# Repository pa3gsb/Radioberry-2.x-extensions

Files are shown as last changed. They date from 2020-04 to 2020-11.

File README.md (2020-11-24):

# Radioberry-2.x-extensions
Hardware extensions to the Radioberry Ham Radio

Deepu Augustin VU3TLD, from India made the next step to make a complete stackable HAM radio.

He started with a Power Amplifier board, based on the G6ALU 20W PA; version 1.5 is available and
the first components are in place.

He also is aiming for a filter board; a version 1.3 is available; first PCB's are underway!

An animation of the idea of such a configuration can be found => Radioberry_radio_assembly.avi file.

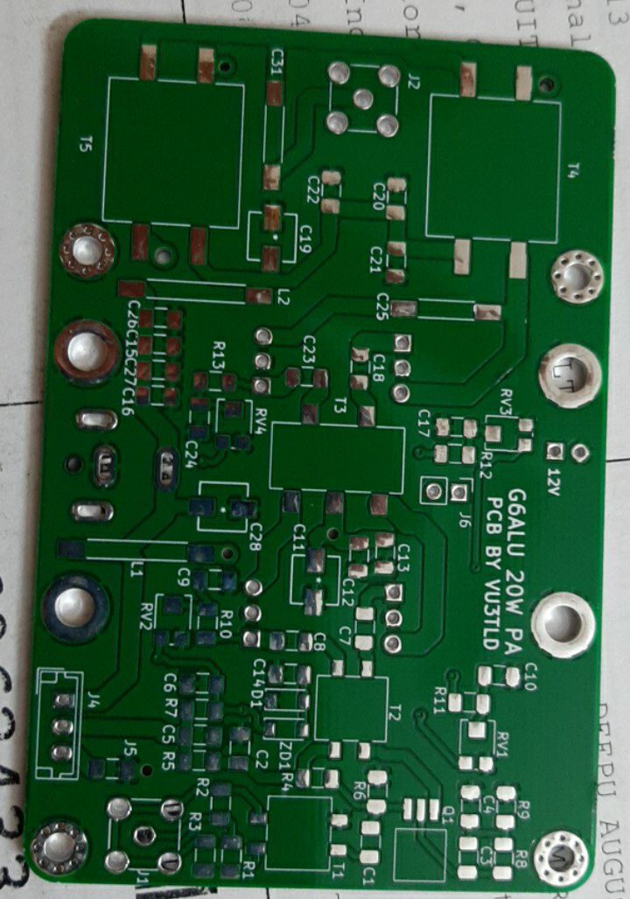
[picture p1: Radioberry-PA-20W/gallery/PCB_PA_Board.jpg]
Radioberry-2.x-extensions

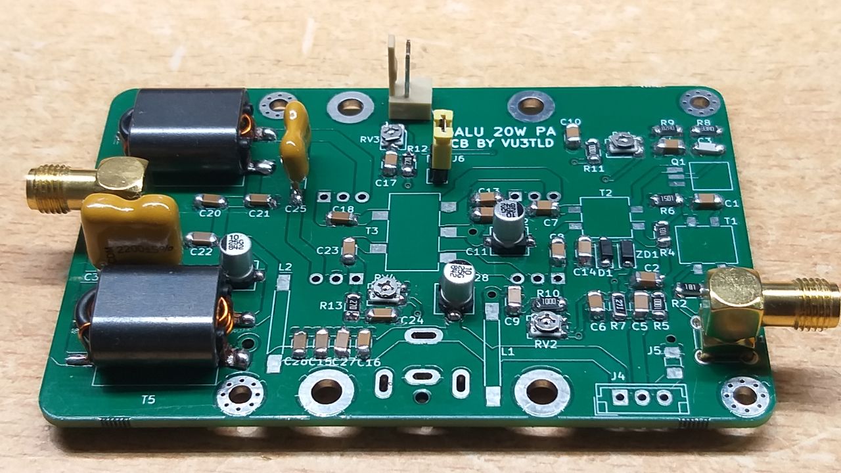
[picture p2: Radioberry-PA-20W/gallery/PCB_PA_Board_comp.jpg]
Radioberry-2.x-extensions

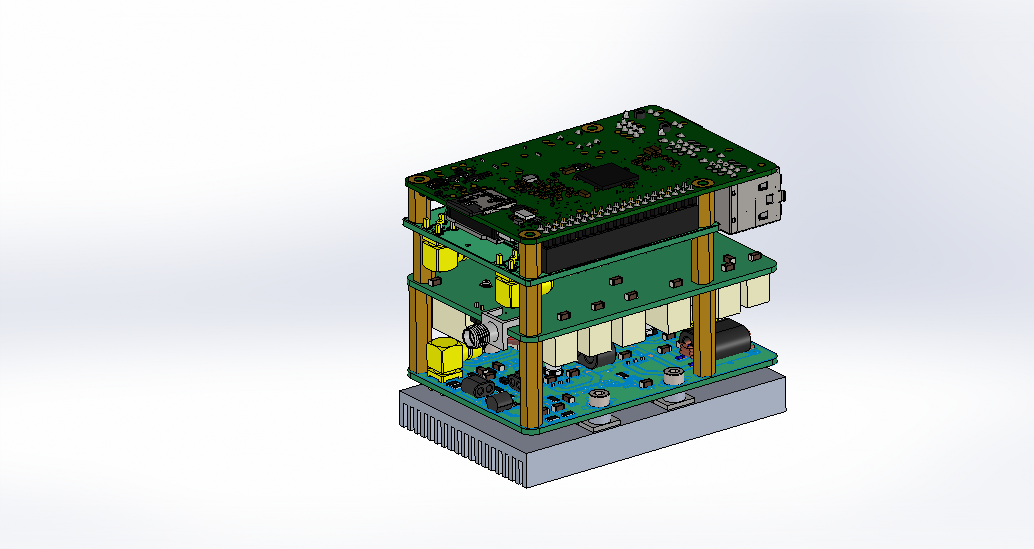
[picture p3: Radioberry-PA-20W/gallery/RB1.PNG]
Radioberry-2.x-extensions

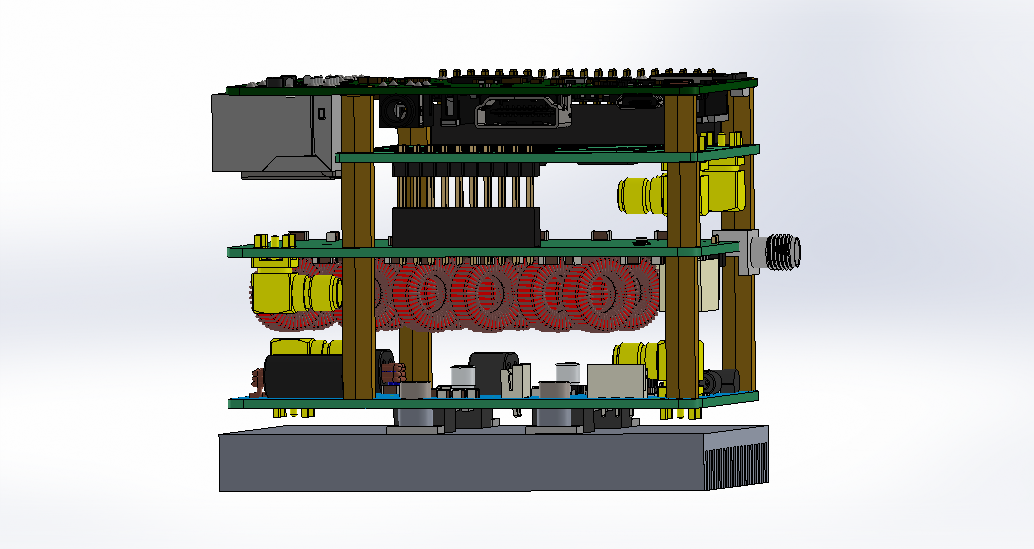
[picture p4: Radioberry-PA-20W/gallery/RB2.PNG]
Radioberry-2.x-extensions

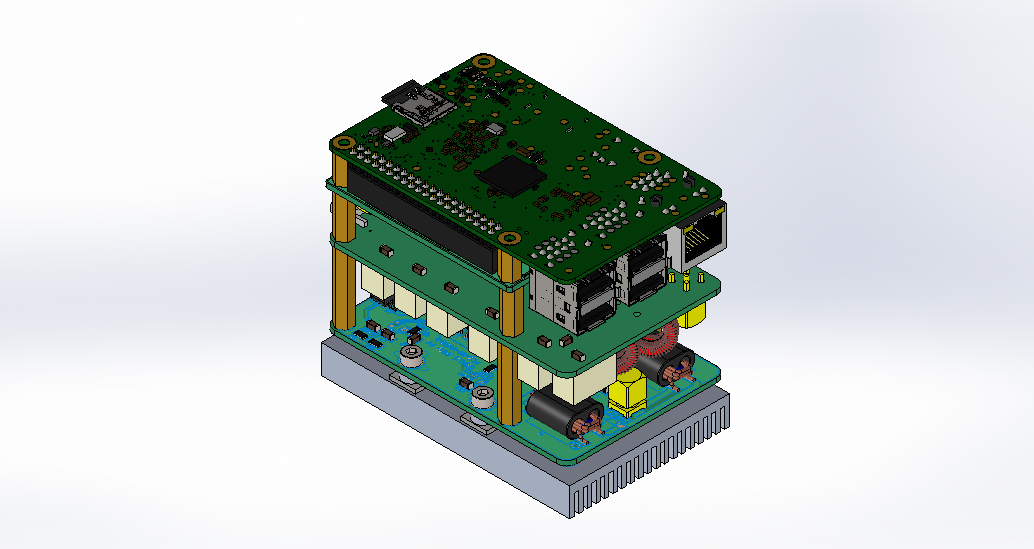
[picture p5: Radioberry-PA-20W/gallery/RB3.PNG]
Radioberry-2.x-extensions

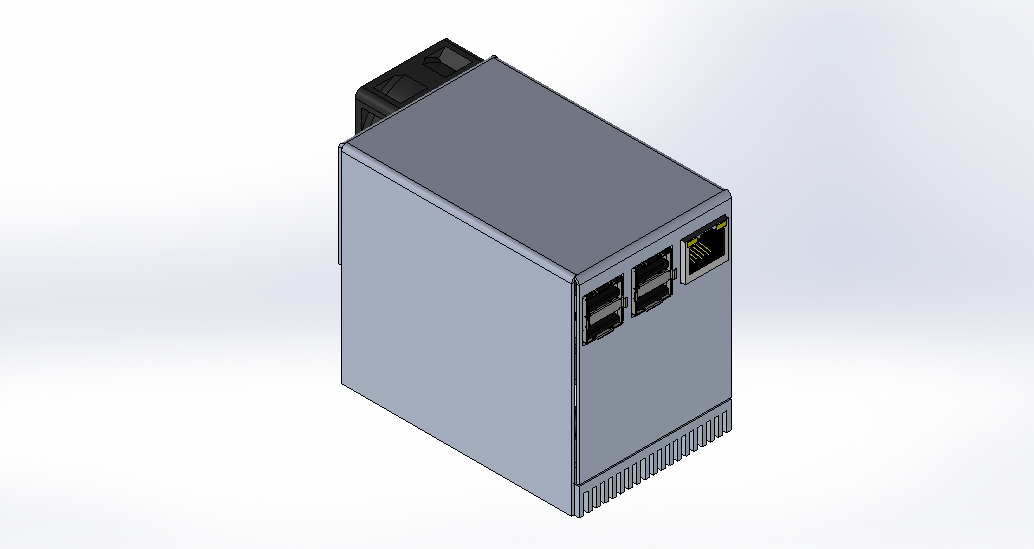
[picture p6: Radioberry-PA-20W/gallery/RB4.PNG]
Radioberry-2.x-extensions


Some nice PA details:

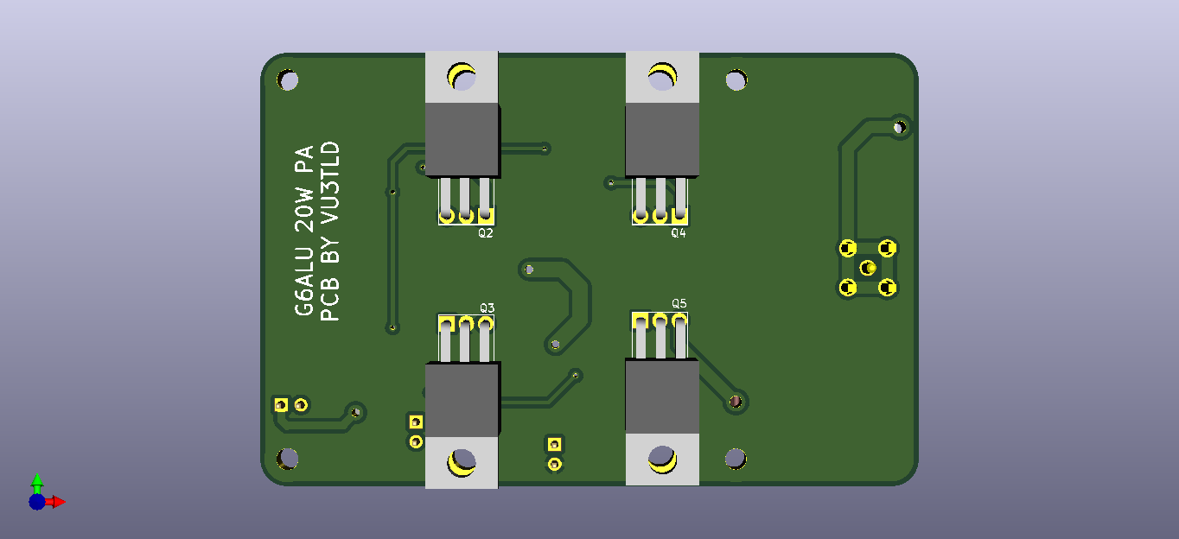
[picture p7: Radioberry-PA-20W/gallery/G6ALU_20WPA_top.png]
Radioberry-2.x-extensions

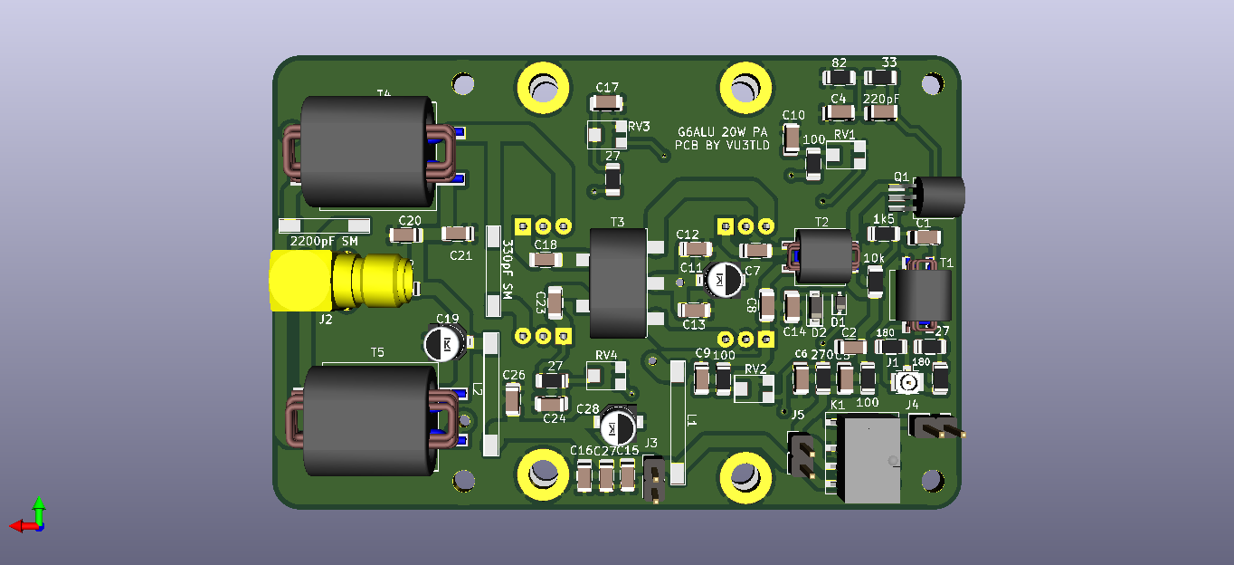
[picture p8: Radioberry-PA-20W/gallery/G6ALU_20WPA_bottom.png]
Radioberry-2.x-extensions


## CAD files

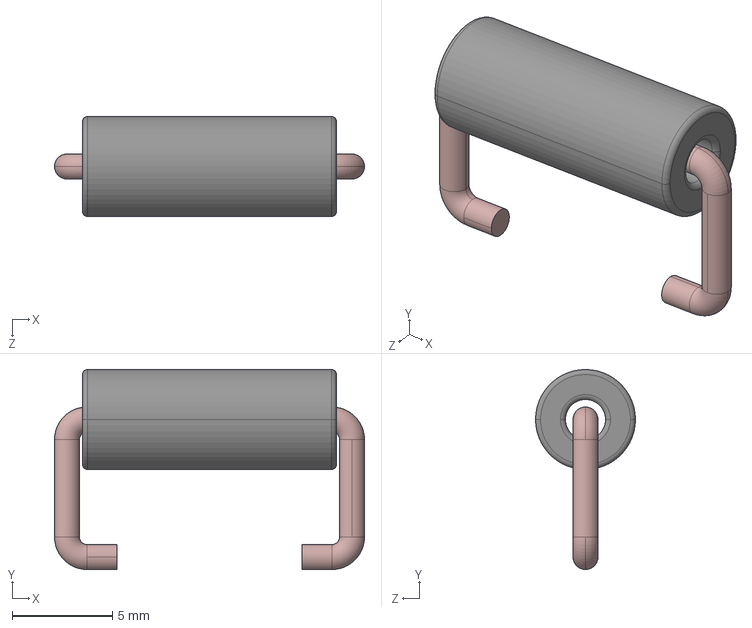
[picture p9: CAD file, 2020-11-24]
Radioberry-PA-20W/3D_Models/Part1.STEP
15.5 x 10.0 x 5.00 mm

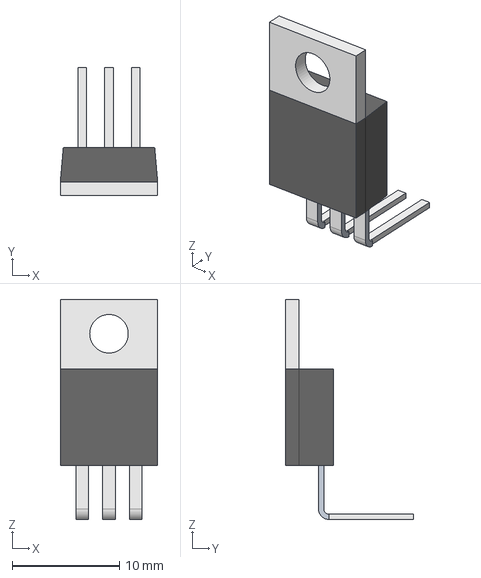
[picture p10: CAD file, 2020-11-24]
Radioberry-PA-20W/3D_Models/TO220.STEP
9.10 x 12.0 x 20.6 mm

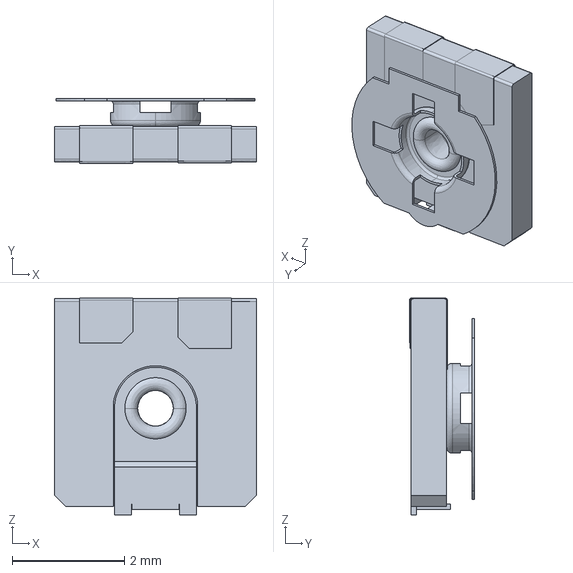
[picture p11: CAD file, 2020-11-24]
Radioberry-PA-20W/3D_Models/TC-33X-1.stp
3.60 x 1.17 x 3.86 mm

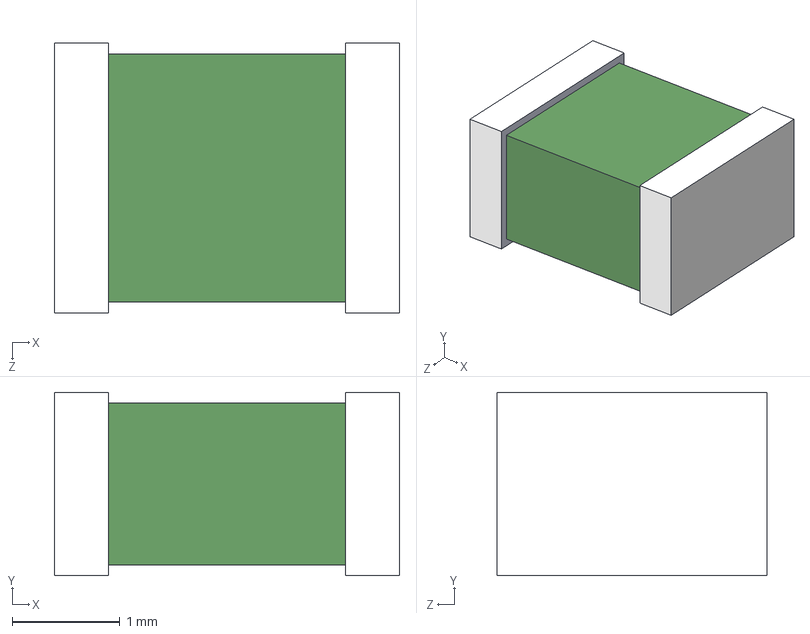
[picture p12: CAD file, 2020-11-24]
Radioberry_LPF_V1.3/Radioberry_LPF_V1.3/3D_ models/Taiyo Yuden_1210.STEP
3.20 x 1.70 x 2.50 mm

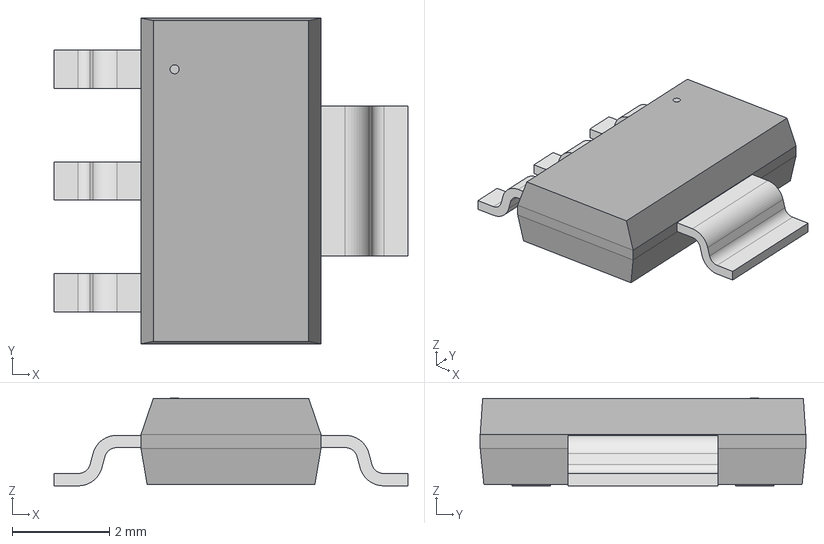
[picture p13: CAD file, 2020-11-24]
Radioberry-PA-20W/3D_Models/MP04A_TEX-M.step
7.29 x 6.71 x 1.81 mm

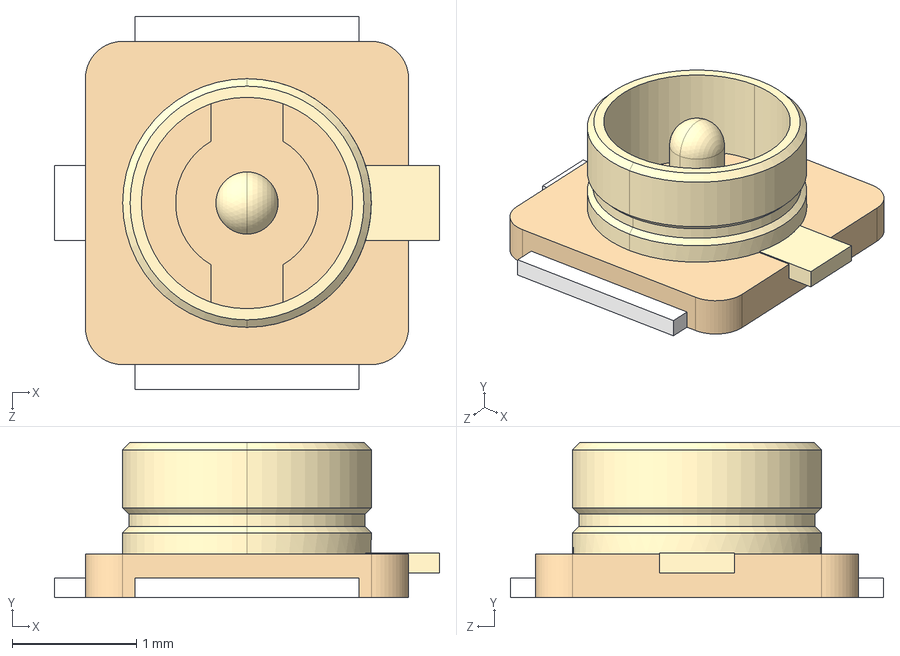
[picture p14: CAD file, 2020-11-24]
Radioberry_LPF_V1.3/Radioberry_LPF_V1.3/3D_ models/U.FL-R-SMT-1_10_.step
3.10 x 1.25 x 3.00 mm

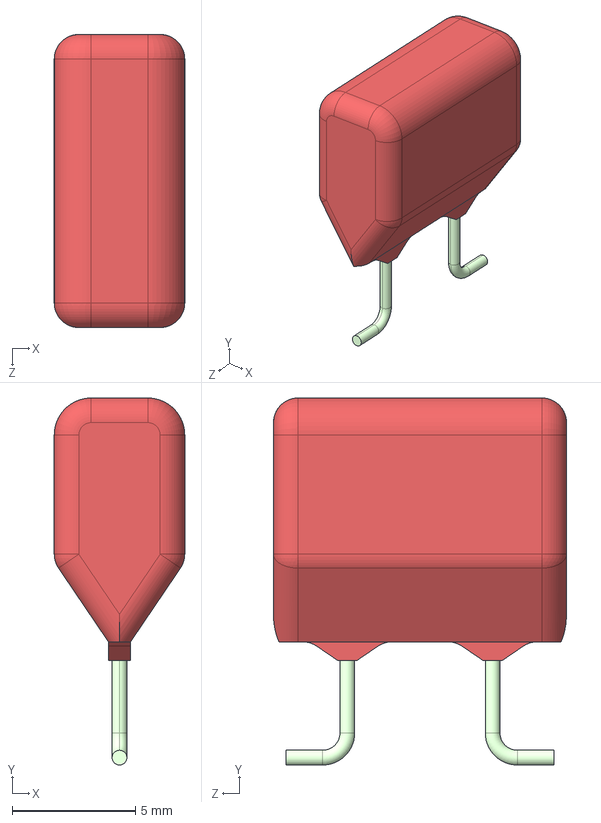
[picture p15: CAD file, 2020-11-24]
Radioberry-PA-20W/3D_Models/CAP330_n.STEP
5.30 x 14.9 x 11.9 mm

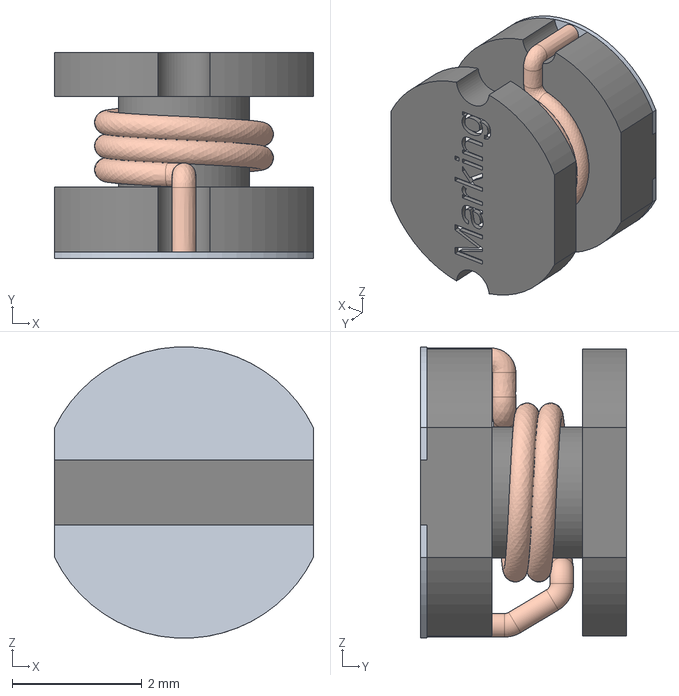
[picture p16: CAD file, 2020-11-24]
Radioberry_LPF_V1.3/Radioberry_LPF_V1.3/3D_ models/WE_744773039.stp
4.00 x 3.18 x 4.49 mm

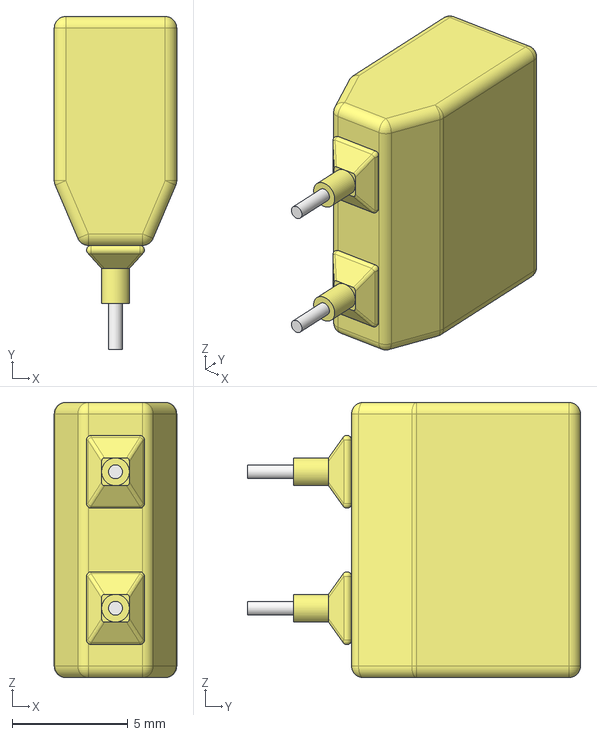
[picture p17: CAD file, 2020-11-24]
Radioberry-PA-20W/3D_Models/CAP330.STEP
5.30 x 14.4 x 11.9 mm

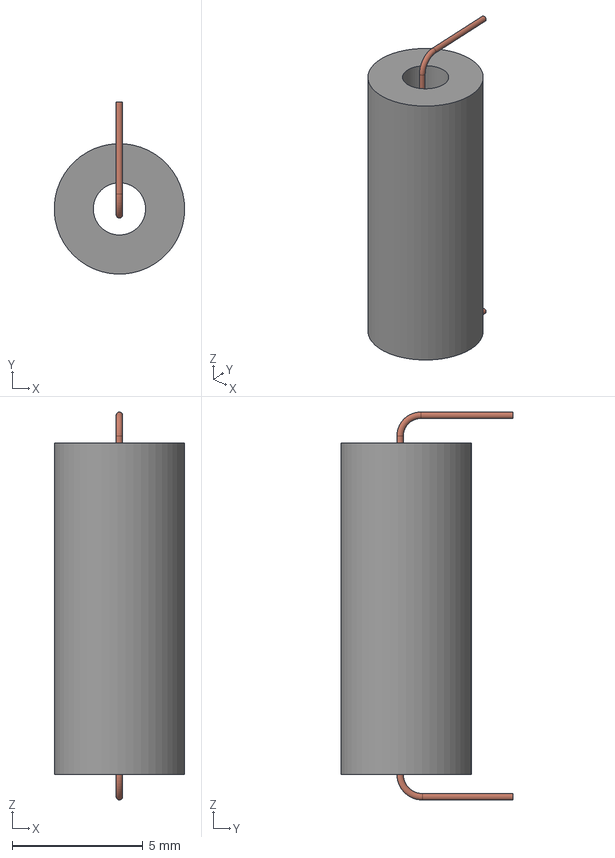
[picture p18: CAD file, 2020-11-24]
Radioberry-PA-20W/3D_Models/ferrite bead_L1.step
5.00 x 6.60 x 14.9 mm

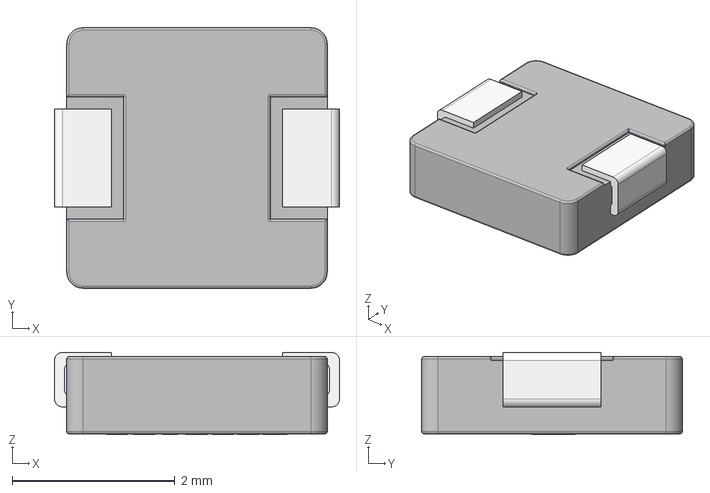
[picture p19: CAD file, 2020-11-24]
Radioberry_LPF_V1.3/Radioberry_LPF_V1.3/3D_ models/SRP3012TA.stp
3.50 x 3.20 x 1.01 mm

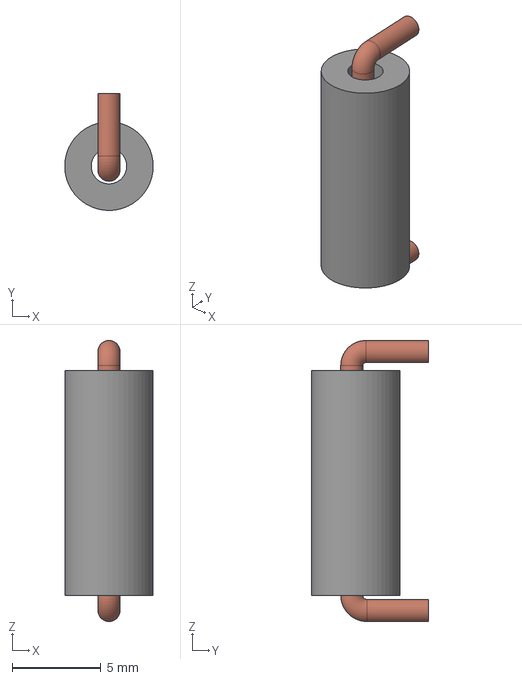
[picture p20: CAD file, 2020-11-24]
Radioberry-PA-20W/3D_Models/ferrite bead_L2.step
5.00 x 6.60 x 15.9 mm

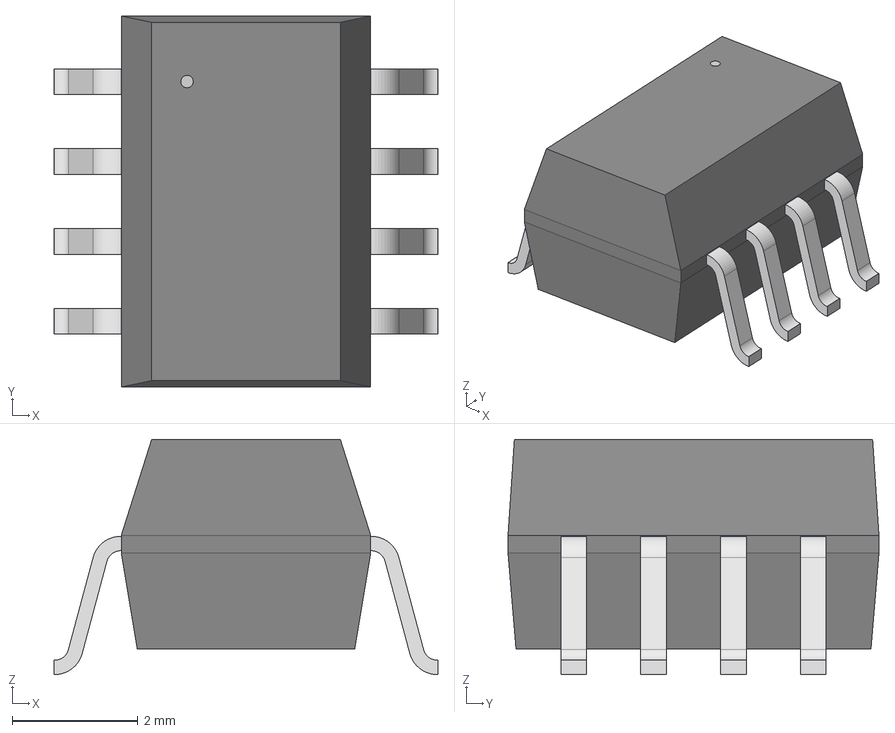
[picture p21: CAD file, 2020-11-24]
Radioberry_LPF_V1.3/Radioberry_LPF_V1.3/3D_ models/SO-8_ILD.step
6.10 x 5.89 x 3.74 mm

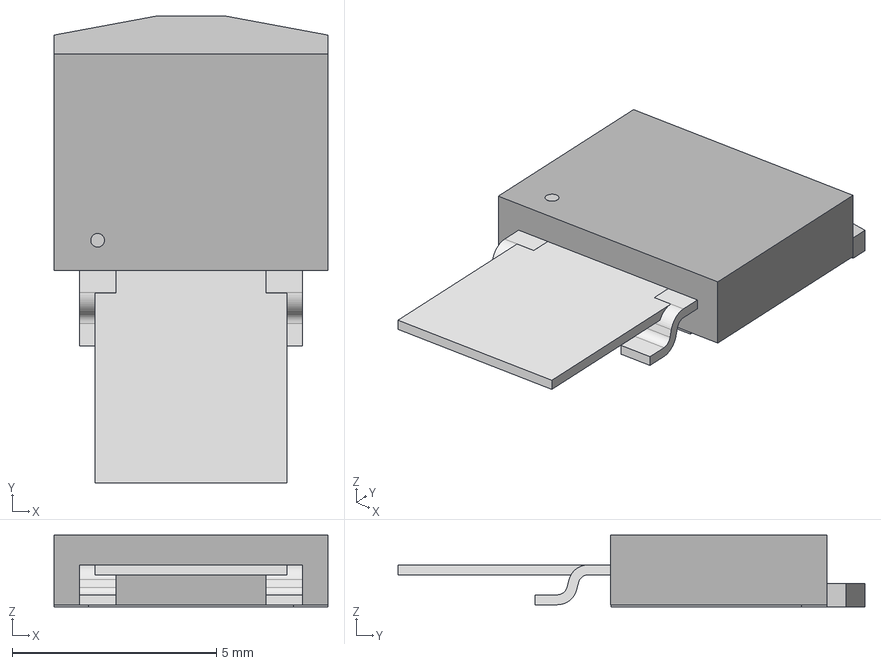
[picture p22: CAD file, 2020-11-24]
Radioberry-PA-20W/3D_Models/KVU3_TEX-M.step
6.71 x 11.4 x 1.75 mm

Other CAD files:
Radioberry_LPF_V1.3/Radioberry_LPF_V1.3/3D_ models/WE_7845.stp
Radioberry-PA-20W/3D_Models/CAP2200_n.STEP
Radioberry_LPF_V1.3/Radioberry_LPF_V1.3/3D_ models/AGQ_(GQ)_Relays.STEP
Radioberry-PA-20W/3D_Models/PJ-063BH.step
Radioberry-PA-20W/3D_Models/BN43-1502.STEP
Radioberry-PA-20W/3D_Models/BN43-1502pin.STEP
Radioberry-PA-20W/3D_Models/BN43-202.STEP
Radioberry-PA-20W/3D_Models/BN43-2402.STEP
Radioberry-PA-20W/3D_Models/CAP2200.STEP
Radioberry-PA-20W/3D_Models/EDH106M025A9BAA.step
Radioberry-PA-20W/3D_Models/SMA-J-P-H-RA-TH1.stp
Radioberry-PA-20W/3D_Models/to92SMD.STEP
Radioberry-PA-20W/DXF/G6ALU_20WPA_V1.5-B_SilkS.dxf
Radioberry-PA-20W/DXF/G6ALU_20WPA_V1.5-F_SilkS.dxf
Radioberry_LPF_V1.3/Radioberry_LPF_V1.3/3D_ models/744040240068.stp
Radioberry_LPF_V1.3/Radioberry_LPF_V1.3/3D_ models/74405042010.stp
Radioberry_LPF_V1.3/Radioberry_LPF_V1.3/3D_ models/74406042010.stp
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

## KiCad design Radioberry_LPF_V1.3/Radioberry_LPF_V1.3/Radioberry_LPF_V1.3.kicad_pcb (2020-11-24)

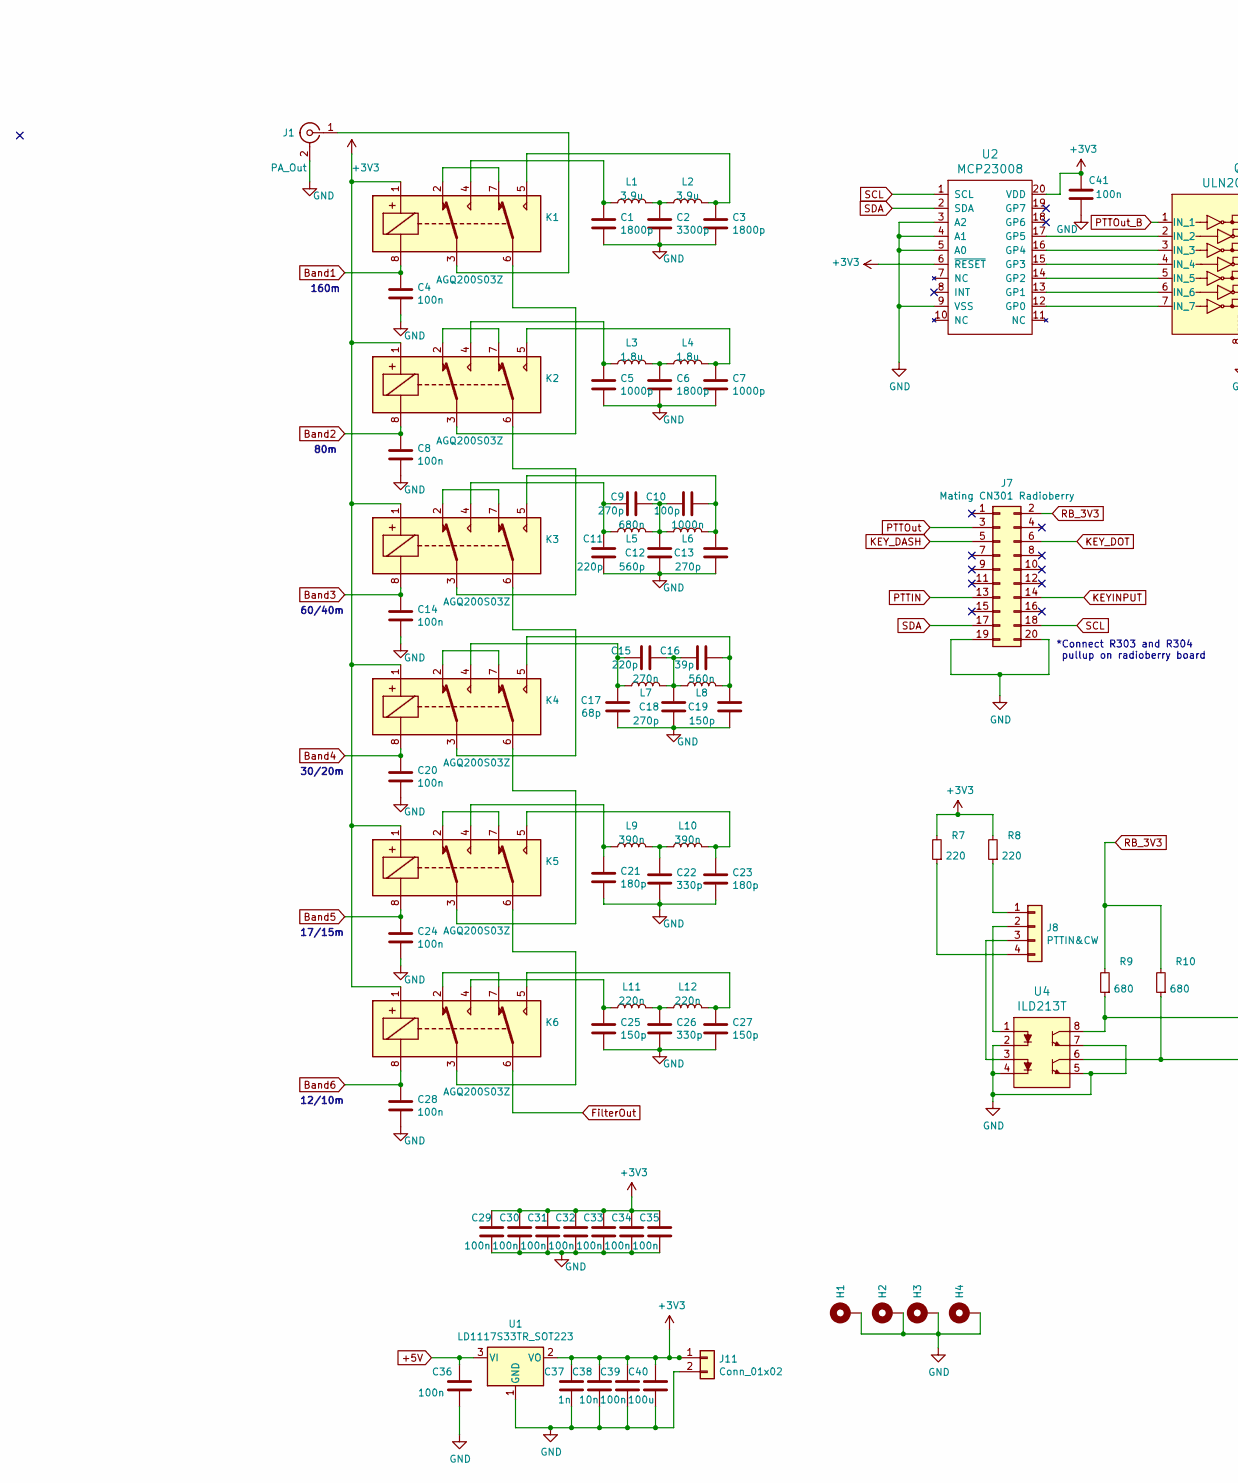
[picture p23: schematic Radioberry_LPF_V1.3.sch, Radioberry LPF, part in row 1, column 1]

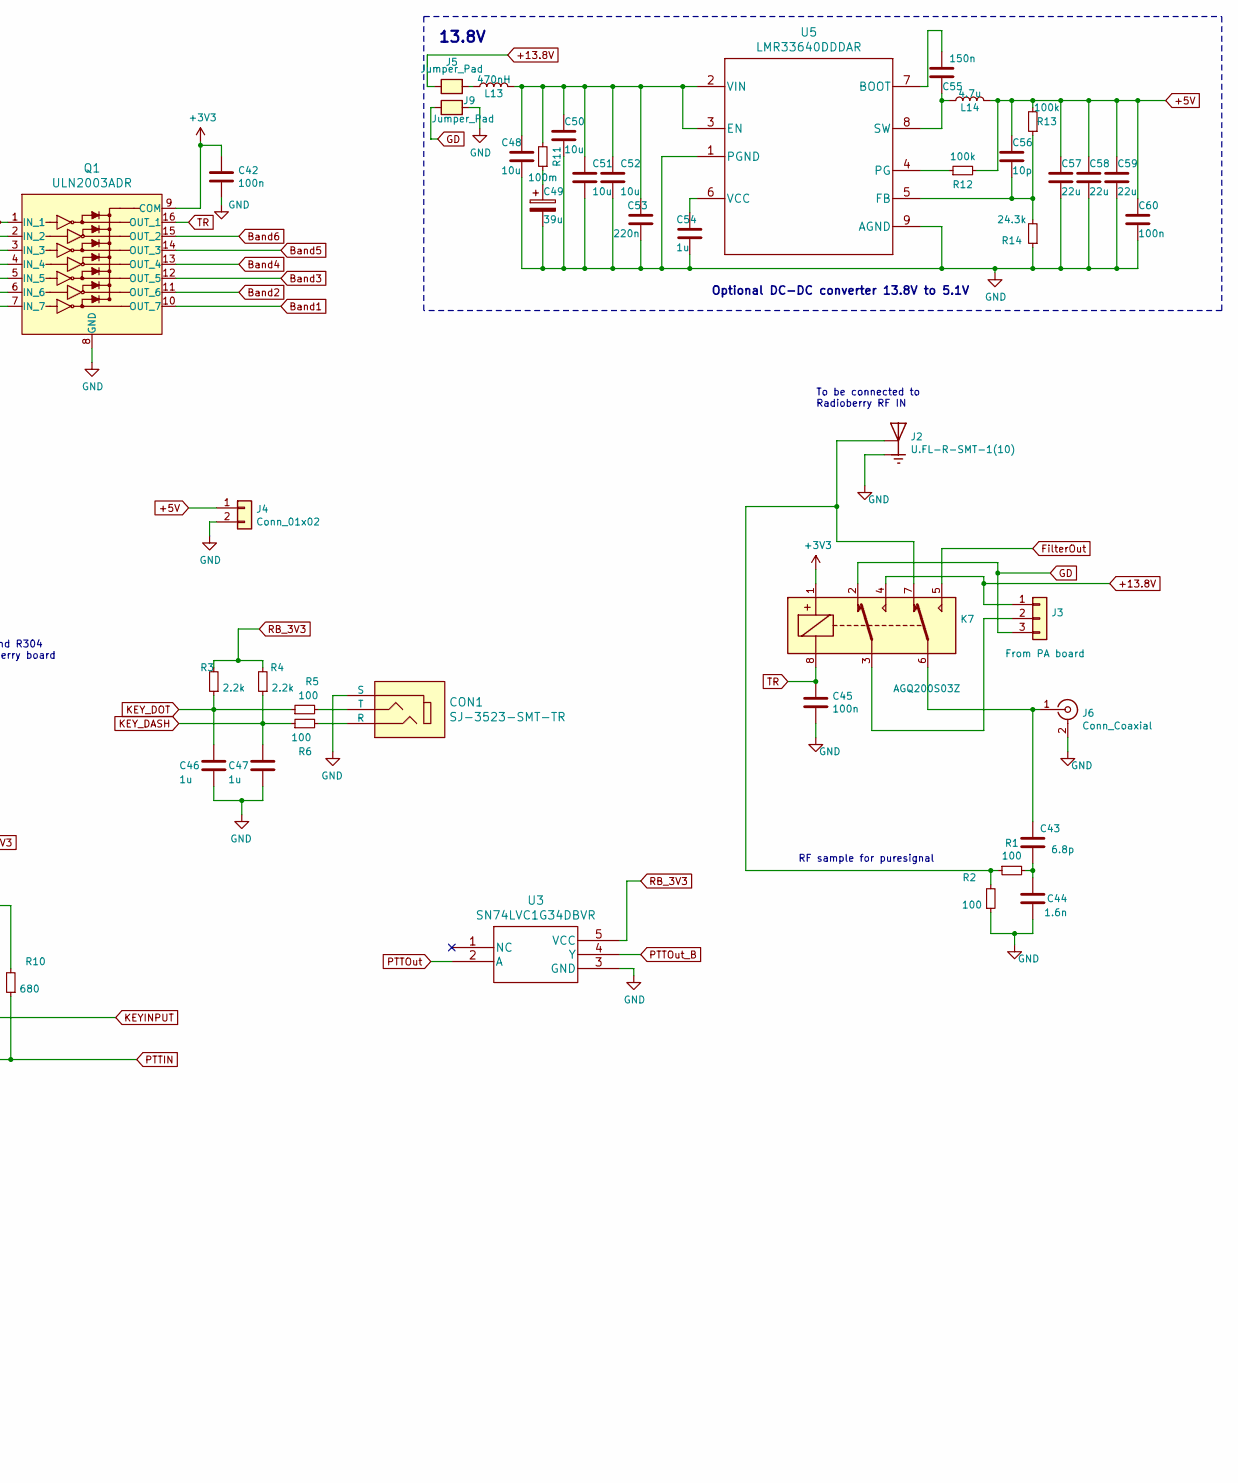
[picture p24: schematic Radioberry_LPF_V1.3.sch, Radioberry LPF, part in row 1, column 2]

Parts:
C1, C3, C6: 1800p; C_0805_2012Metric_Pad1.18x1.45mm_HandSolder; MPN GRM2165C2A182JA01D
C2: 3300p; C_0805_2012Metric_Pad1.18x1.45mm_HandSolder; MPN VJ0805A332JXBTW1BC
C4, C8, C14, C20, C24, C28, C29, C30, C31, C32, C33, C34, C35, C36, C39, C41, C42, C45: 100n; C_0805_2012Metric_Pad1.18x1.45mm_HandSolder; MPN 08055C104KAT2A
C5, C7: 1000p; C_0805_2012Metric_Pad1.18x1.45mm_HandSolder; MPN 885012007088
C9, C13, C18: 270p; C_0805_2012Metric_Pad1.18x1.45mm_HandSolder; MPN CC0805JRNPO0BN271
C10: 100p; C_0805_2012Metric_Pad1.18x1.45mm_HandSolder; MPN 885012007082
C11, C15: 220p; C_0805_2012Metric_Pad1.18x1.45mm_HandSolder; MPN 08051A221JAT2A
C12: 560p; C_0805_2012Metric_Pad1.18x1.45mm_HandSolder; MPN CC0805JRNPO0BN561
C16: 39p; C_0805_2012Metric_Pad1.18x1.45mm_HandSolder; MPN 08051A390JAT2A
C17: 68p; C_0805_2012Metric_Pad1.18x1.45mm_HandSolder; MPN C0805C680J1GACTU
C19, C25, C27: 150p; C_0805_2012Metric_Pad1.18x1.45mm_HandSolder; MPN AC0805JRNPO0BN151
C21, C23: 180p; C_0805_2012Metric_Pad1.18x1.45mm_HandSolder; MPN 08051A181JAT2A
C22, C26: 330p; C_0805_2012Metric_Pad1.18x1.45mm_HandSolder; MPN C0805C331J1GACTU
C37: 1n; C_0805_2012Metric_Pad1.18x1.45mm_HandSolder; MPN 08055C102KAT2A
C38: 10n; C_0805_2012Metric_Pad1.18x1.45mm_HandSolder; MPN 08051C103KAT2A
C40: 100u; C_1206_3216Metric; MPN CL31A107MQHNNWE
C43: 6.8p; C_0805_2012Metric_Pad1.18x1.45mm_HandSolder; MPN AC0805JRNPO0BN151
C44: 1.6n; C_0805_2012Metric_Pad1.18x1.45mm_HandSolder; MPN AC0805JRNPO0BN151
C46, C47: 1u; C_0805_2012Metric_Pad1.18x1.45mm_HandSolder; MPN C0805C105K4RACTU
C48, C50, C51, C52: 10u; C_1206_3216Metric; MPN GRM31CR61E106KA12L
C49: 39u; 16SVPC39MV; MPN 16SVPC39MV
C53: 220n; C_0603_1608Metric_Pad1.08x0.95mm_HandSolder; MPN GRM188R71E224KA88D
C54: 1u; C_0603_1608Metric_Pad1.08x0.95mm_HandSolder; MPN C0603C105Z8VACTU
C55: 150n; C_0603_1608Metric_Pad1.08x0.95mm_HandSolder; MPN GRM188R71A154KA01D
C56: 10p; C_0603_1608Metric_Pad1.08x0.95mm_HandSolder; MPN GRM1885C1H100JA01D
C57, C58, C59: 22u; C_0805_2012Metric; MPN GRM21BR61A226ME44L
C60: 100n; C_0603_1608Metric_Pad1.08x0.95mm_HandSolder; MPN GRM188R71H104KA93D
CON1: SJ-3523-SMT-TR; MPN SJ-3523-SMT-TR; Digi-Key_PN CP-3523SJCT-ND
H1, H2, H3, H4: MountingHole_Pad; MountingHole_2.7mm_Pad
J1: PA_Out; SMA_Amphenol_132291_Vertical
J2: U.FL-R-SMT-1(10); HRS_U.FL-R-SMT-1(10)
J3: From PA board; PinHeader_1x03_P2.54mm_Vertical
J4, J11: Conn_01x02; PinHeader_1x02_P2.54mm_Vertical
J5, J9: Jumper_Pad; Jumper_0805
J6: Conn_Coaxial; SMA_Amphenol_132289_EdgeMount
J7: Mating CN301 Radioberry; PinSocket_2x10_P2.54mm_Vertical
J8: PTTIN&CW; JST_GH_SM04B-GHS-TB_1x04-1MP_P1.25mm_Horizontal
K1, K2, K3, K4, K5, K6, K7: AGQ200S03Z
L1, L2: 3.9u; 744773039; MPN 744773039
L3, L4: 1.8u; 7440450018; MPN 7440450018
L5: 680n; WE-LQS; MPN 744040240068
L6: 1000n; 74406042010; MPN 74406042010
L7: 270n; Taiyo_Yuden_1210; MPN BR L3225TR27M
L8: 560n; 744089430056; MPN 744089430056
L9, L10: 390n; WE-SPC_SMD_4828; MPN 744089420039
L11, L12: 220n; WE-SPC_SMD_4818; MPN 744089410022
L13: 470nH; NLCV32T-R47M-PFR; MPN NLCV32T-R47M-PFR
L14: 4.7u; WE-XHMI_SMD_6060; MPN 74439346047
Q1: ULN2003ADR; SOIC-16_3.9x9.9mm_P1.27mm; MPN ULN2003ADR; Digi-Key_PN 296-1368-1-ND
R1: 100; R_0805_2012Metric
R2, R5, R6: 100; R_0805_2012Metric_Pad1.20x1.40mm_HandSolder
R3, R4: 2.2k; R_0805_2012Metric_Pad1.20x1.40mm_HandSolder
R7, R8: 220; R_0805_2012Metric_Pad1.20x1.40mm_HandSolder
R9, R10: 680; R_0805_2012Metric_Pad1.20x1.40mm_HandSolder
R11: 100m; R_0603_1608Metric_Pad0.98x0.95mm_HandSolder; MPN ERJ-3RSFR10V
R12, R13: 100k; R_0603_1608Metric_Pad0.98x0.95mm_HandSolder; MPN CRCW0603100KFKEA
R14: 24.3k; R_0603_1608Metric_Pad0.98x0.95mm_HandSolder; MPN CRCW060324K3FKEA
U1: LD1117S33TR_SOT223; SOT-223-3_TabPin2
U2: MCP23008; SSOP-20_3.9x8.7mm_P0.635mm; MPN MCP23008-E/P; Digi-Key_PN MCP23008-E/P-ND
U3: SN74LVC1G34DBVR; MPN SN74LVC1G34DBVR
U4: ILD213T; MPN ILD213T
U5: LMR33640DDDAR; MPN LMR33640DDDAR

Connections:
+3V3: C29.1, C30.1, C31.1, C32.1, C33.1, C34.1, C35.1, C37.1, C38.1, C39.1, C40.1, C41.1, C42.1, J11.1, K1.1, K2.1, K3.1, K4.1, K5.1, K6.1, K7.1, Q1.9 (COM), R7.2, R8.2, U1.2 (VO), U2.6 (~RESET), U2.20 (VDD)
+5V: C36.1, C56.1, C57.1, C58.1, C59.1, C60.1, J4.1, L14.2, R12.2, R13.2, U1.3 (VI)
+13.8V: J3.1, J5.2, K7.4
Band1: C4.1, K1.8, Q1.10 (OUT_7)
Band2: C8.1, K2.8, Q1.11 (OUT_6)
Band3: C14.1, K3.8, Q1.12 (OUT_5)
Band4: C20.1, K4.8, Q1.13 (OUT_4)
Band5: C24.1, K5.8, Q1.14 (OUT_3)
Band6: C28.1, K6.8, Q1.15 (OUT_2)
FilterOut: K6.6, K7.5
GD: J3.3, J9.2, K7.2
GND: C1.2, C2.2, C3.2, C4.2, C5.2, C6.2, C7.2, C8.2, C11.2, C12.2, C13.2, C14.2, C17.2, C18.2, C19.2, C20.2, C21.2, C22.2, C23.2, C24.2, C25.2, C26.2, C27.2, C28.2, C29.2, C30.2, C31.2, C32.2, C33.2, C34.2, C35.2, C36.2, C37.2, C38.2, C39.2, C40.2, C41.2, C42.2, C44.2, C45.2, C46.2, C47.2, C48.2, C49.2, C50.2, C51.2, C52.2, C53.2, C54.2, C57.2, C58.2, C59.2, C60.2, CON1.1 (S), H1.1, H2.1, H3.1, H4.1, J1.2 (Ext), J2.1, J2.3, J4.2, J6.2 (Ext), J7.19, J7.20, J9.1, J11.2, Q1.8 (GND), R2.1, R14.1, U1.1 (GND), U2.3 (A2), U2.4 (A1), U2.5 (A0), U2.9 (VSS), U3.3 (GND), U4.2, U4.4, U4.5, U4.7, U5.1 (PGND), U5.9 (AGND)
KEYINPUT: J7.14, R9.1, U4.8
KEY_DASH: C47.1, J7.5, R4.1, R6.1
KEY_DOT: C46.1, J7.6, R3.1, R5.1
unnamed: C1.1, K1.4, L1.1
unnamed: C2.1, L1.2, L2.1
unnamed: C3.1, K1.5, L2.2
unnamed: C5.1, K2.4, L3.1
unnamed: C6.1, L3.2, L4.1
unnamed: C7.1, K2.5, L4.2
unnamed: C9.2, C10.1, C12.1, L5.1, L6.2
unnamed: C10.2, C13.1, K3.5, L6.1
unnamed: C9.1, C11.1, K3.4, L5.2
unnamed: C15.1, C17.1, K4.4, L7.2
unnamed: C15.2, C16.1, C18.1, L7.1, L8.2
unnamed: C16.2, C19.1, K4.5, L8.1
unnamed: C21.1, K5.4, L9.1
unnamed: C22.1, L9.2, L10.1
unnamed: C23.1, K5.5, L10.2
unnamed: C25.1, K6.4, L11.1
unnamed: C26.1, L11.2, L12.1
unnamed: C27.1, K6.5, L12.2
unnamed: C43.1, J6.1 (In), K7.6
unnamed: C43.2, C44.1, R1.2
unnamed: C48.1, C50.1, C51.1, C52.1, C53.1, L13.2, R11.2, U5.2 (VIN), U5.3 (EN)
unnamed: C49.1, R11.1
unnamed: C54.1, U5.6 (VCC)
unnamed: C55.1, U5.7 (BOOT)
unnamed: C55.2, L14.1, U5.8 (SW)
unnamed: C56.2, R13.1, R14.2, U5.5 (FB)
unnamed: CON1.2 (T), R5.2
unnamed: CON1.3 (R), R6.2
unnamed: J1.1 (In), K1.3
unnamed: J2.2, K7.7, R1.1, R2.2
unnamed: J3.2, K7.3
unnamed: J5.1, L13.1
unnamed: J8.1, R8.1
unnamed: J8.2, U4.1
unnamed: J8.3, U4.3
unnamed: J8.4, R7.1
unnamed: K1.2, K1.7
unnamed: K1.6, K2.3
unnamed: K2.2, K2.7
unnamed: K2.6, K3.3
unnamed: K3.2, K3.7
unnamed: K3.6, K4.3
unnamed: K4.2, K4.7
unnamed: K4.6, K5.3
unnamed: K5.2, K5.7
unnamed: K5.6, K6.3
unnamed: K6.2, K6.7
unnamed: Q1.2 (IN_2), U2.17 (GP5)
unnamed: Q1.3 (IN_3), U2.16 (GP4)
unnamed: Q1.4 (IN_4), U2.15 (GP3)
unnamed: Q1.5 (IN_5), U2.14 (GP2)
unnamed: Q1.6 (IN_6), U2.13 (GP1)
unnamed: Q1.7 (IN_7), U2.12 (GP0)
unnamed: R12.1, U5.4 (PG)
PTTIN: J7.13, R10.1, U4.6
PTTOut: J7.3, U3.2 (A)
PTTOut_B: Q1.1 (IN_1), U3.4 (Y)
RB_3V3: J7.2, R3.2, R4.2, R9.2, R10.2, U3.5 (VCC)
SCL: J7.18, U2.1 (SCL)
SDA: J7.17, U2.2 (SDA)
TR: C45.1, K7.8, Q1.16 (OUT_1)

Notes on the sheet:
To be connected to Radioberry RF IN
RF sample for puresignal
Optional DC-DC converter 13.8V to 5.1V
13.8V
*Connect R303 and R304 pullup on radioberry board
12/10m
17/15m
30/20m
60/40m
80m
160m

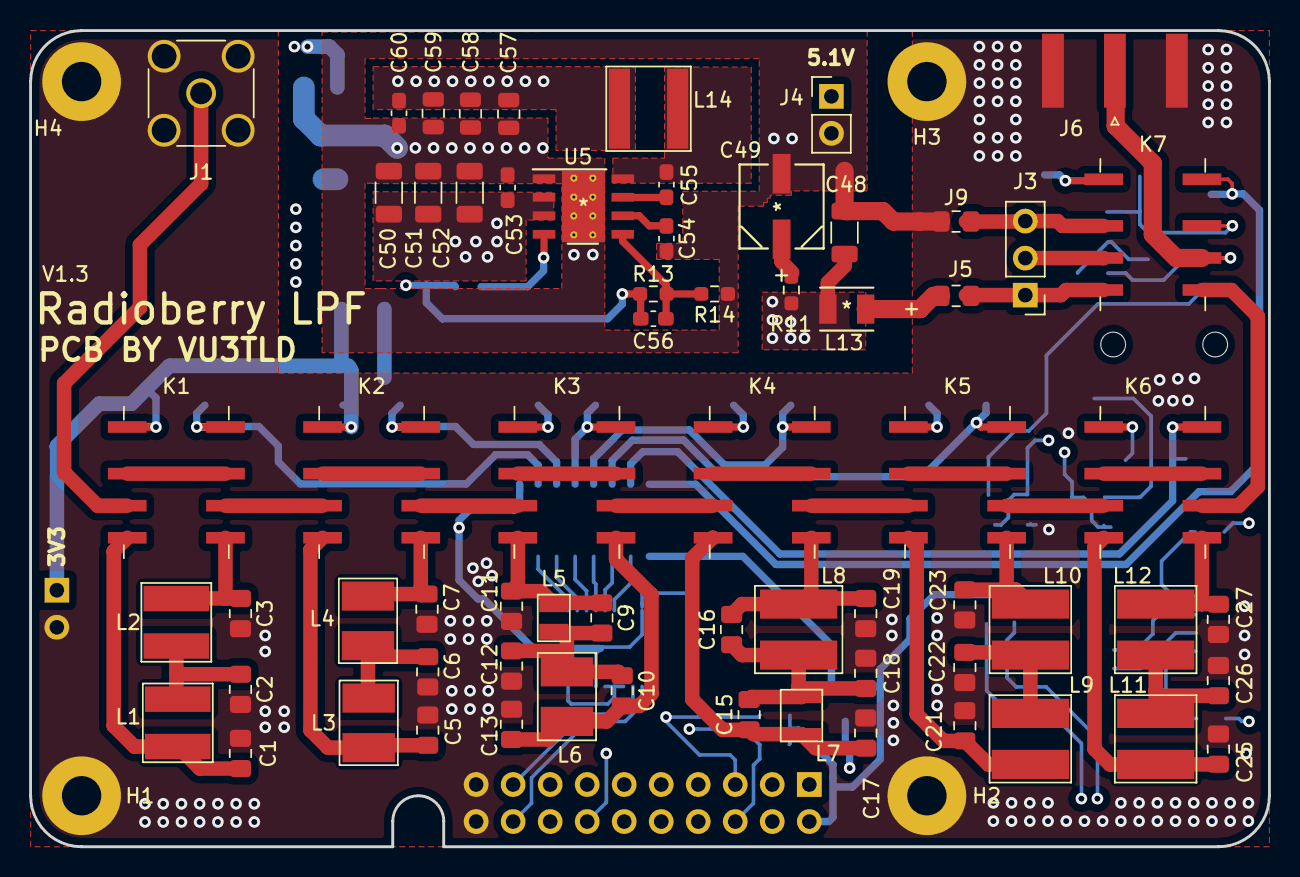
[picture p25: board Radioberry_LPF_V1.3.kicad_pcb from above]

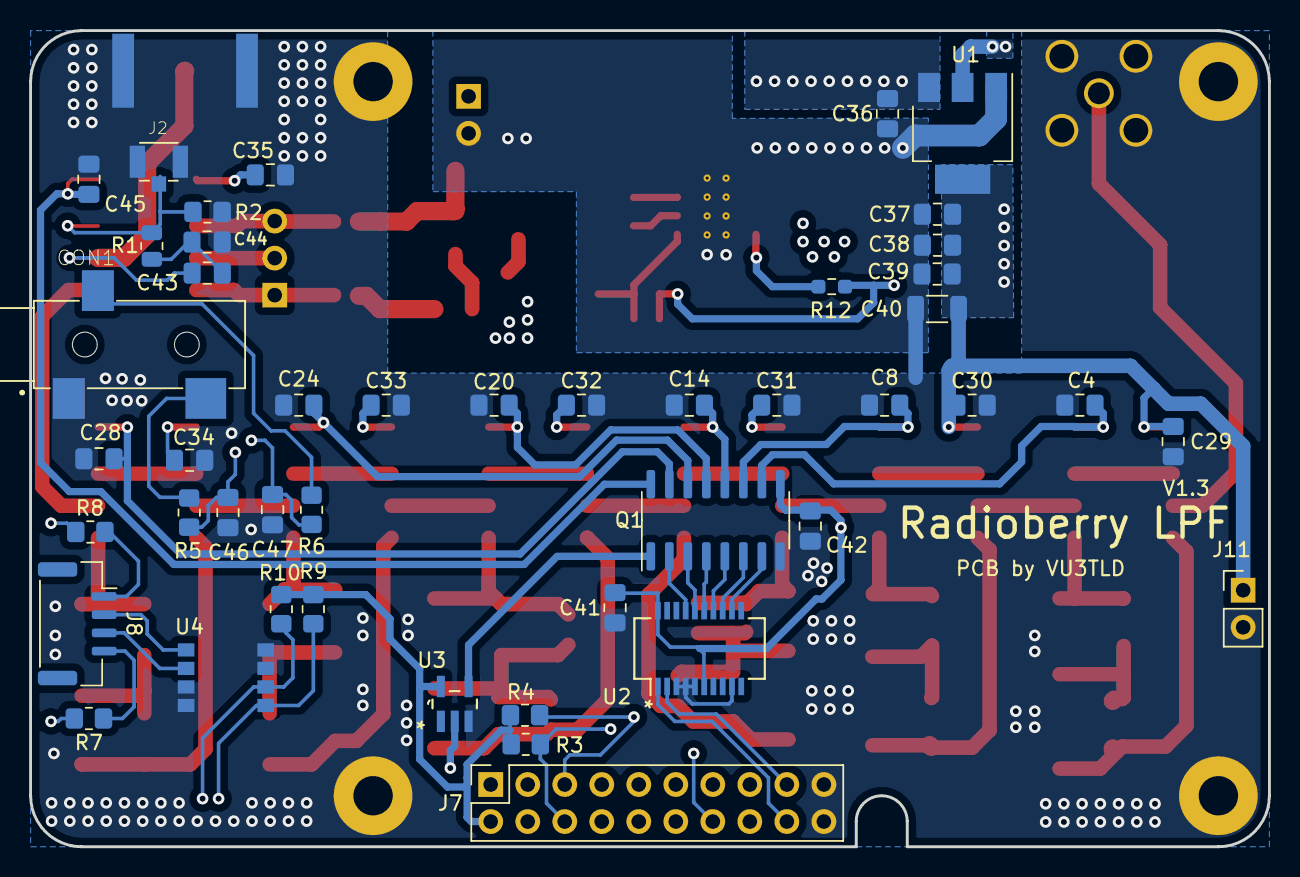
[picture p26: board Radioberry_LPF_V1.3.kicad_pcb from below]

Board: 4 copper layers, 85.0 x 56.0 mm, 116 parts (46 on the bottom side), 76 nets.

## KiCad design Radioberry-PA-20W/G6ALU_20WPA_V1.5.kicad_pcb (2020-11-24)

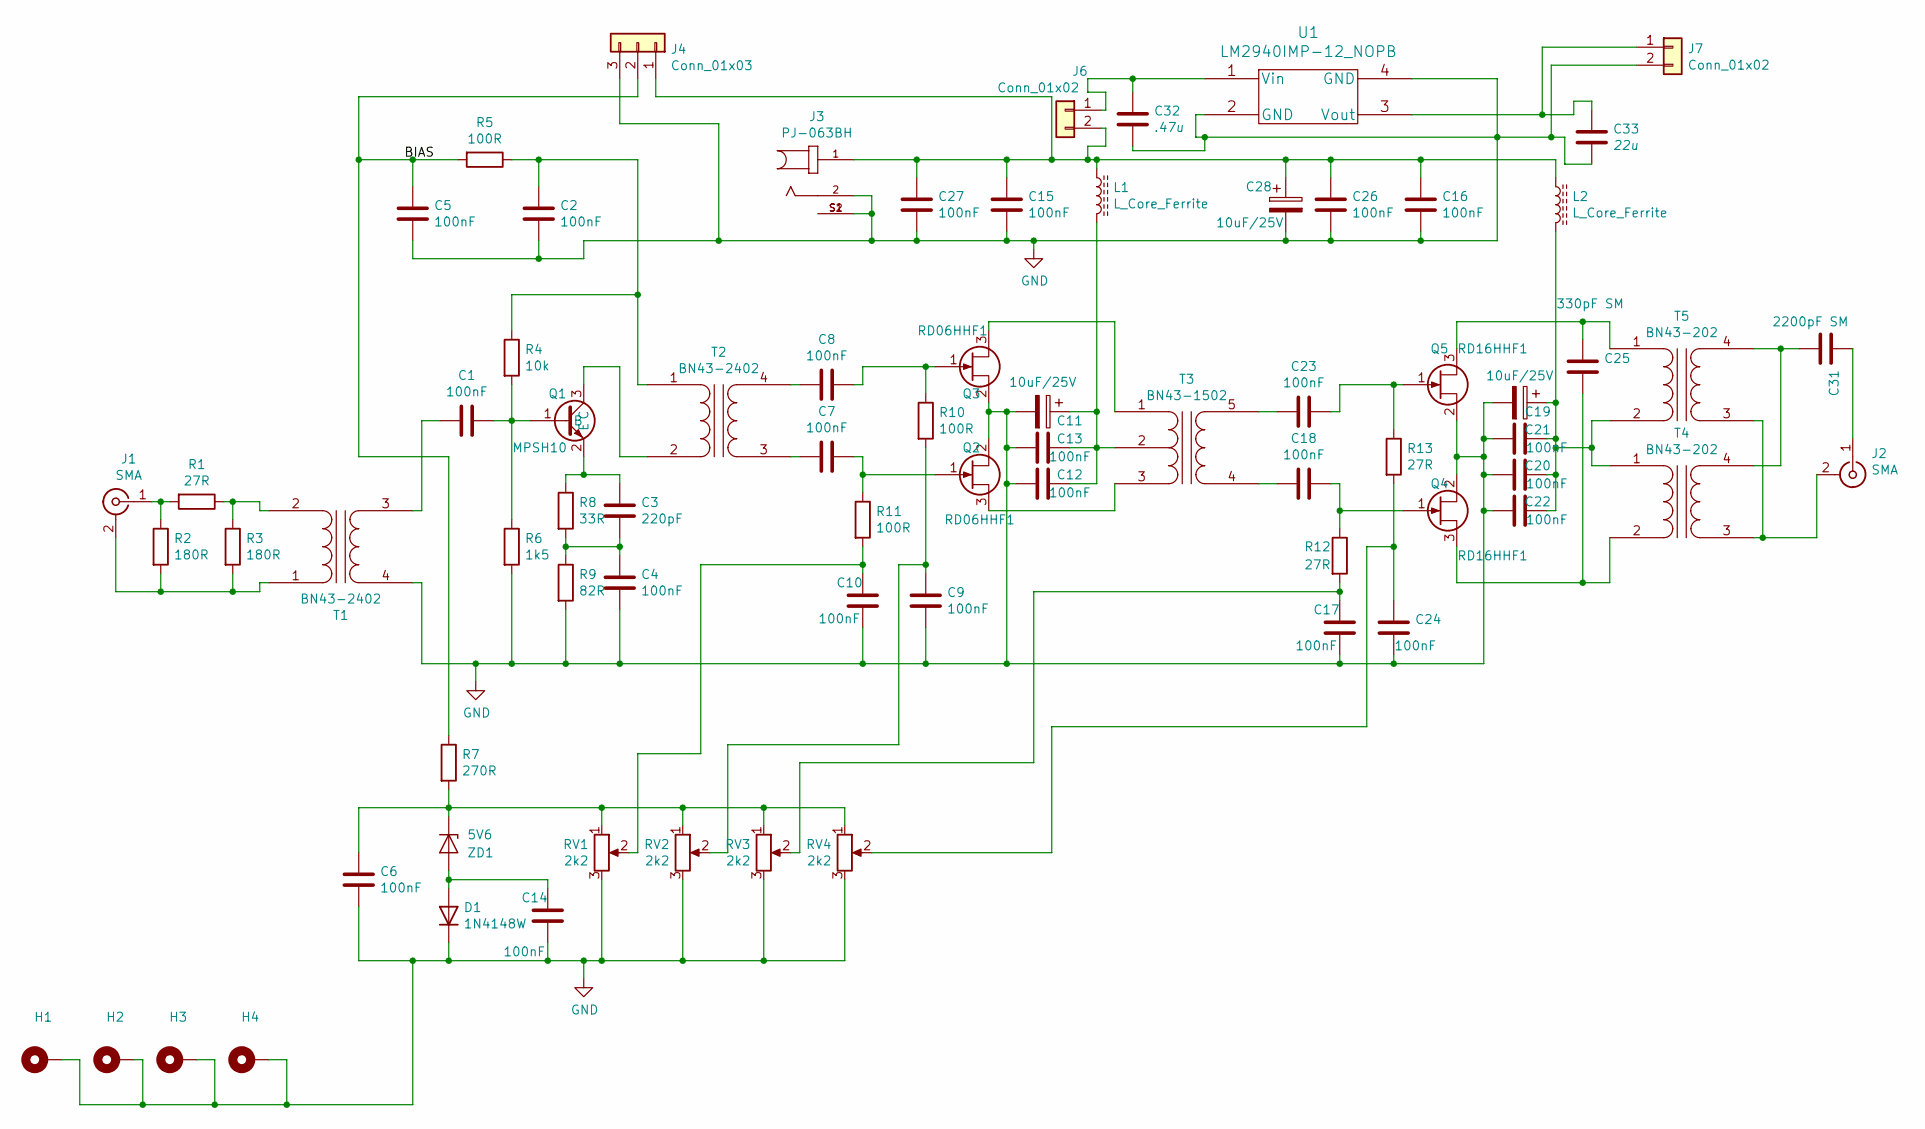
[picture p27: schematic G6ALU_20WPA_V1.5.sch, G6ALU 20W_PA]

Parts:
C1, C2, C4, C5, C6, C7, C8, C9, C10, C12, C13, C14, C15, C16, C17, C18, C20, C21, C22, C23, C24, C26, C27: 100nF; C_1206_3216Metric_Pad1.33x1.80mm_HandSolder; Part No. C1206X104K1RAC3316
C3: 220pF; C_1206_3216Metric_Pad1.33x1.80mm_HandSolder; Part No. C1206C221J5GACTU
C11, C19, C28: 10uF/25V; EDK106M025A9BAA; Part No. EDK106M025A9BAA
C25: 330pF SM; CD15FD331JO3; Part No. CD15FD331JO3
C31: 2200pF SM; CD16FD222JO3F; Part No. CD16FD222JO3F
C32: .47u; C_1206_3216Metric_Pad1.33x1.80mm_HandSolder; Part No. CL21B474KBFNNNE
C33: 22u; C_1206_3216Metric_Pad1.33x1.80mm_HandSolder; Part No. CL31A226KAHNNNE
D1: 1N4148W; D_SOD-123; Part No. 1N4148W-E3-08
H1, H2, H3, H4: MountingHole_Pad; MountingHole_2.7mm_Pad_Via
J1, J2: SMA; SMA_RightAngle
J3: PJ-063BH; CUI_PJ-063BH; Part No. PJ-063BH
J4: Conn_01x03; JST_EH_B3B-EH-A_1x03_P2.50mm_Vertical
J6, J7: Conn_01x02; PinHeader_1x02_P2.54mm_Vertical
L1: L_Core_Ferrite; FB_TH_L1; Part No. 901330-01
L2: L_Core_Ferrite; FB_TH_L2; Part No. 901330-01
Q1: MPSH10; TO-92_SMD; Part No. MPSH10
Q2, Q3: RD06HHF1; TO-220_HRZ; Part No. RD06HHF1
Q4, Q5: RD16HHF1; TO-220_HRZ; Part No. RD16HHF1
R1, R12, R13: 27R; R_1206_3216Metric_Pad1.30x1.75mm_HandSolder; Part No. RC1206JR-0727RL
R2, R3: 180R; R_1206_3216Metric_Pad1.30x1.75mm_HandSolder; Part No. RC1206JR-07180RL
R4: 10k; R_1206_3216Metric_Pad1.30x1.75mm_HandSolder; Part No. RC1206JR-0710KL
R5, R10, R11: 100R; R_1206_3216Metric_Pad1.30x1.75mm_HandSolder; Part No. RC1206FR-07100RL
R6: 1k5; R_1206_3216Metric_Pad1.30x1.75mm_HandSolder; Part No. RC1206FR-071K5L
R7: 270R; R_1206_3216Metric_Pad1.30x1.75mm_HandSolder; Part No. ERJ-P08J271V
R8: 33R; R_1206_3216Metric_Pad1.30x1.75mm_HandSolder; Part No. RC1206FR-0733RL
R9: 82R; R_1206_3216Metric_Pad1.30x1.75mm_HandSolder; Part No. RC1206FR-0782RL
RV1, RV2, RV3, RV4: 2k2; POT; Part No. TC33X-1-222E
T1, T2: BN43-2402; Part No. BN43-2402
T3: BN43-1502; Part No. BN43-1502
T4, T5: BN43-202; BN43-202_TH; Part No. BN43-202
U1: LM2940IMP-12_NOPB; LM2940IMP-12&slash_NOPB; Part No. LM2940IMP-12/NOPB
ZD1: 5V6; D_SOD-123; Part No. BZT52C5V6-E3-08

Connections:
/BIAS: C5.2, J4.2, R5.2, R7.1
GND: C2.1, C4.1, C5.1, C6.1, C9.1, C10.1, C11.2, C12.1, C13.1, C14.1, C15.1, C16.1, C17.1, C19.2, C20.2, C21.2, C22.2, C24.1, C26.1, C27.1, C28.2, C32.1, C33.1, D1.1 (K), H1.1, H2.1, H3.1, H4.1, J3.2, J3.S1 (SHIELD), J3.S2 (SHIELD), J4.3, J7.2, Q2.2 (S), Q3.2 (S), Q4.2 (S), Q5.2 (S), R6.2, R9.2, RV1.3, RV2.3, RV3.3, RV4.3, T1.4 (SB), U1.2 (GND), U1.4 (GND)
unnamed: C1.1, Q1.1 (B), R4.2, R6.1
unnamed: C1.2, T1.3 (SA)
unnamed: C2.2, R4.1, R5.1, T2.1 (AA)
unnamed: C3.1, C4.2, R8.2, R9.1
unnamed: C3.2, Q1.2 (E), R8.1
unnamed: C6.2, R7.2, RV1.1, RV2.1, RV3.1, RV4.1, ZD1.1 (K)
unnamed: C7.1, Q2.1 (G), R11.1
unnamed: C7.2, T2.3 (SA)
unnamed: C8.1, Q3.1 (G), R10.1
unnamed: C8.2, T2.4 (SB)
unnamed: C9.2, R10.2, RV2.2
unnamed: C10.2, R11.2, RV1.2
unnamed: C11.1, C12.2, C13.2, L1.2, T3.2 (PM)
unnamed: C14.2, D1.2 (A), ZD1.2 (A)
unnamed: C15.2, C16.2, C26.2, C27.2, C28.1, J3.1, J4.1, J6.2, L1.1, L2.1
unnamed: C17.2, R12.2, RV3.2
unnamed: C18.1, Q4.1 (G), R12.1
unnamed: C18.2, T3.4 (S1)
unnamed: C19.1, C20.1, C21.1, C22.1, L2.2, T4.1 (AA), T5.2 (AB)
unnamed: C23.1, Q5.1 (G), R13.1
unnamed: C23.2, T3.5 (S2)
unnamed: C24.2, R13.2, RV4.2
unnamed: C25.1, Q4.3 (D), T4.2 (AB)
unnamed: C25.2, Q5.3 (D), T5.1 (AA)
unnamed: C31.1, T4.4 (SB), T5.4 (SB)
unnamed: C31.2, J2.1 (In)
unnamed: C32.2, J6.1, U1.1 (Vin)
unnamed: C33.2, J7.1, U1.3 (Vout)
unnamed: J1.1 (In), R1.2, R2.1
unnamed: J1.2 (Ext), R2.2, R3.2, T1.1 (AA)
unnamed: J2.2 (Ext), T4.3 (SA), T5.3 (SA)
unnamed: Q1.3 (C), T2.2 (AB)
unnamed: Q2.3 (D), T3.3 (PR2)
unnamed: Q3.3 (D), T3.1 (PR1)
unnamed: R1.1, R3.1, T1.2 (AB)

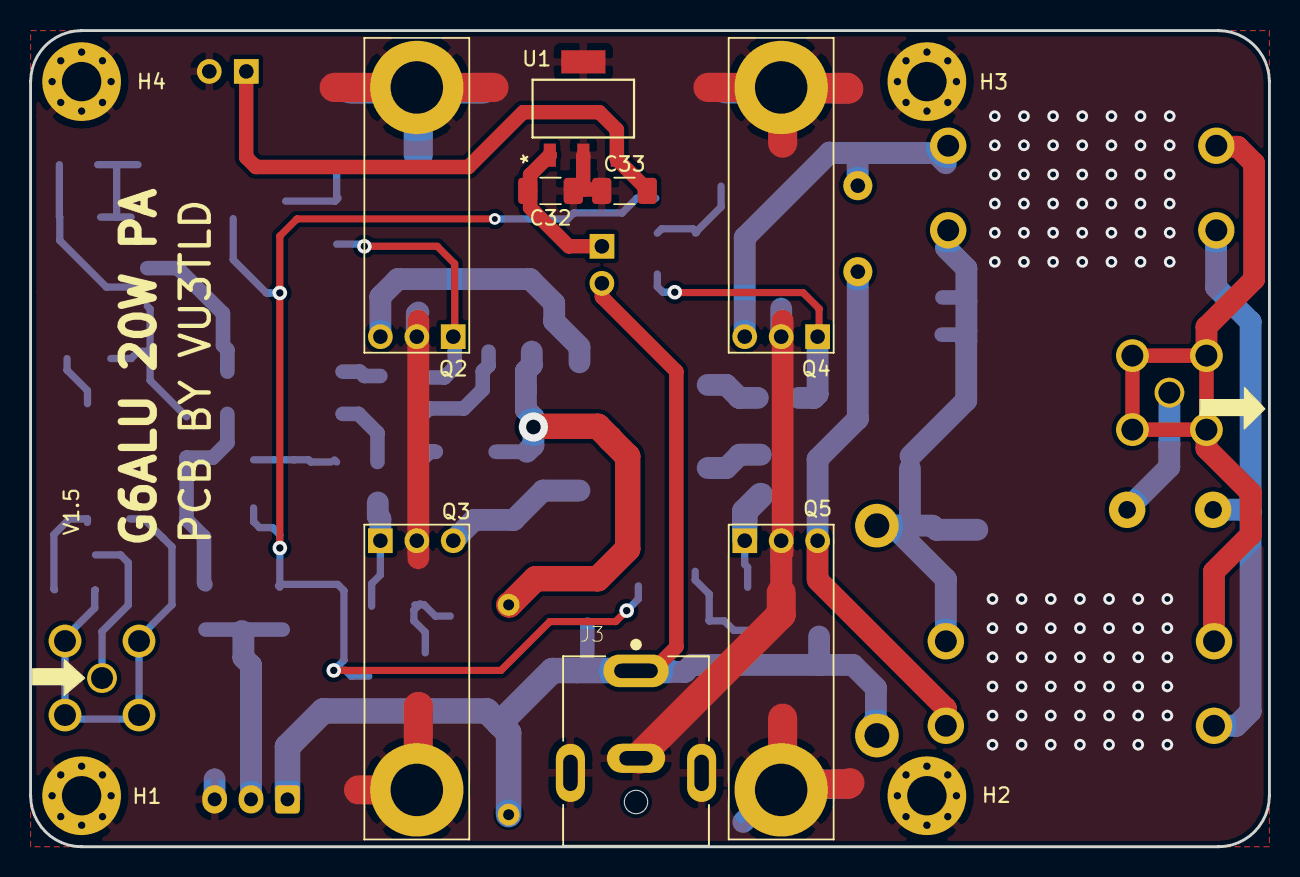
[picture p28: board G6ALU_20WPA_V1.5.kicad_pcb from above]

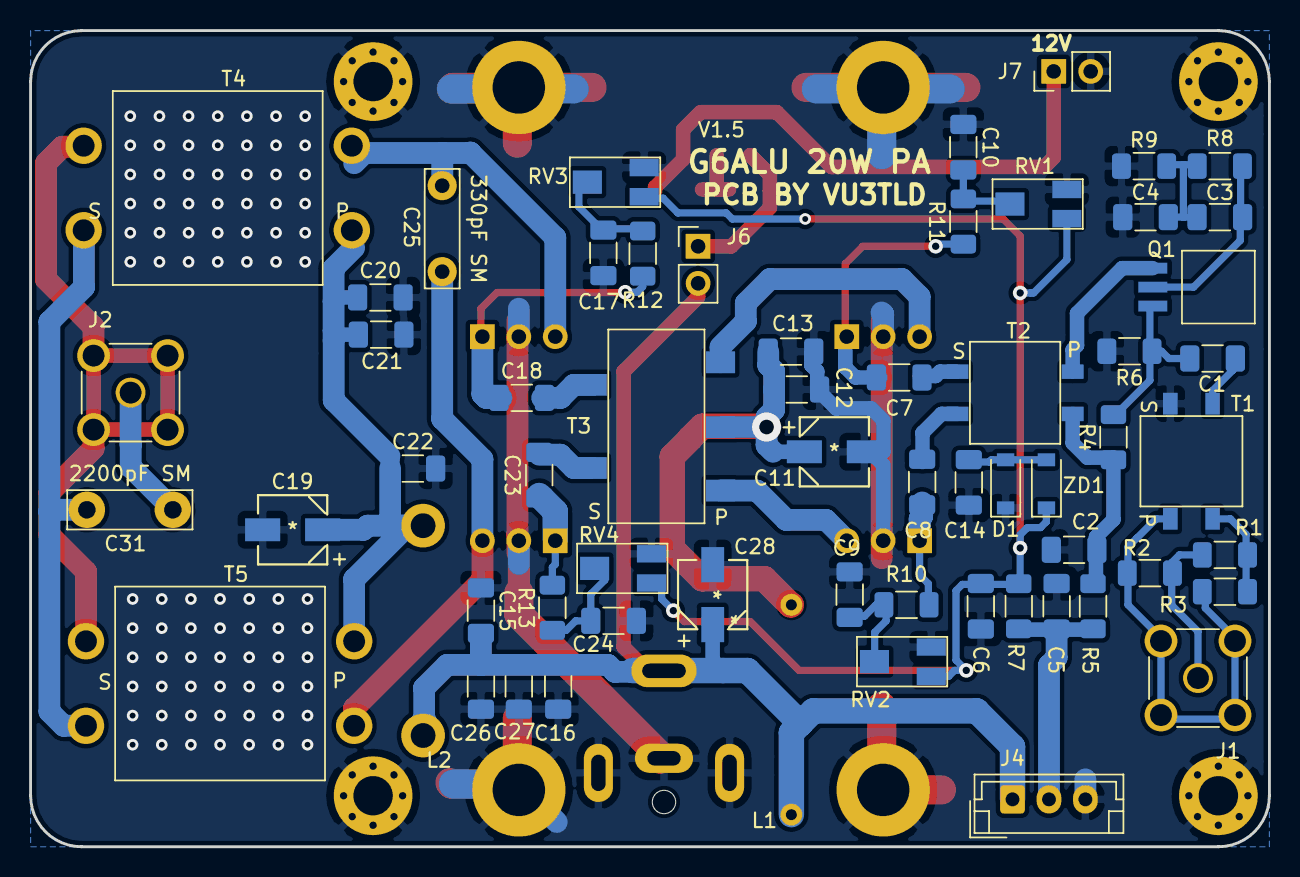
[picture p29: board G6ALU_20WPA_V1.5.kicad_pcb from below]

Board: 2 copper layers, 85.0 x 56.0 mm, 73 parts (61 on the bottom side), 37 nets.

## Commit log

2020-04-24 project init
    [BN43-1502.STEP, BN43-1502pin.STEP, BN43-202.STEP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]
2020-11-24 1.5 PA and 1.3 filter
    [744040240068.stp, 74405042010.stp, 74406042010.stp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]

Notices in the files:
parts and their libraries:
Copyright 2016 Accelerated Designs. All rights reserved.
